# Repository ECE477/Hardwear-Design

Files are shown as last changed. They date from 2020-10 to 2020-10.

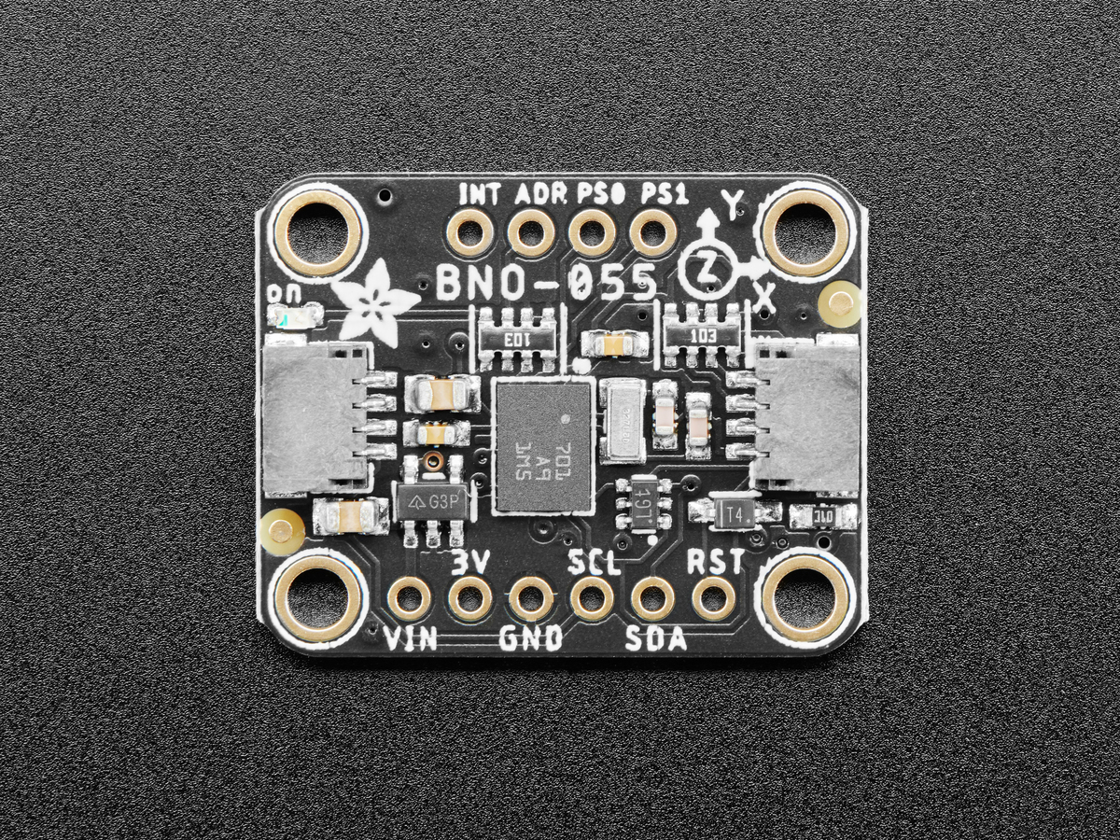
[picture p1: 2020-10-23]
Docs/Adafruit-BNO055-Breakout-PCB-master/Adafruit-BNO055-Breakout-PCB-master/assets/4646.jpg

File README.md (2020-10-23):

# Hardwear Design
Schematic and PCB

## PCB Checklist
### 1 Parts Completion Check
- [x] All major componenets included (ie. Micro, Power Supply, Regulation, Battery Management, IMU, GPS, LoRa, TOLED, Push Buttons, Reset Button, Signal LEDS)
- [x] All support components included (ie. Micro minimum connections, Testing Circuit, Support components package and value(R,Caps,Ind), Application circuits)
#### Other
- [x] Progamming Header 
- [x] Reset Circuit
- [x] Power Connectors
- [x] Mounting holes
- [x] Heartbeat LED
- [x] Debugging LEDs (Transmit LED)
### 2 PCB Footprint Verification Check
- [x] All parts fir on 1:1 scale printout of PCB
### 3 Parts Placement Check
- [x] Oscillator close to Micro? (N/A)
- [x] Decoupling caps close to/under related ICs?
- [x] Connectors on board edges?
- [x] Parts grouped by system and/or in reasonable way that minimizes routing?
### 4 Mechanical/Space Conflict Check:
- [x] Has x- and y- footprint space around electrical pins and pads of all parts been accounted for?
- [x] Has z-height of all parts been accounted for?
- [x] Has clearance been provided for the bolt heads of all mounting holes?
- [x] Have connectors been placed on the outer edges of boards where appropriate? Are they overhanging edges of boards where appropriate? Are they oriented in the correct direction?
- [x] Are all mounting and mechanical support holes free of traces and other electrical items?
### 5 Routing Completion Check:
- [x] All traces routed? (In Eagle, the ratsnest command will say “nothing to do”)
- [x] Oscillator traces clear of interfering signals?
- [x] Traces of appropriate widths to handle current being passed? (Including power traces)
- [x] Traces entering pads at 90-degree angles (or 45 degree angles, where appropriate)?
### 6 Routing Minimization Check:
- [x] Trace lengths have been minimized where possible?
- [x] Octagonal (45-degree constrained) layout mode has been utilized, where possible?
- [x] Right angles have been removed, except where necessary?
- [x] Acute angles have been eliminated from all board routing?
### 7 Via Minimization Check:
- [x] Vias have been eliminated to extent reasonable?
- [x] Signal planes on opposite sides of boards are connected by vias at reasonable intervals?
- [x] Signal Plane Check:
- [x] Signal planes have been included, where reasonable?
- [x] Analog ground (AGND), has been separated from the main ground net in accordance with microcontroller datasheets?
- [x] Isolation on all signal planes has been set to at least 12 mils?
### 9 Silkscreen check
- [x] Silkscreen labels have been provided for all component IDs and connector signal names?
- [x] Silkscreen labels have been appropriately placed near components, but not on top of pads or pins?
- [x] Pin 1 of all ICs and other polarity-sensitive components (such as diodes) is clearly marked?
- [x] Board silkscreen layer includes course and team number "ECE477 Group <x>"?
- [x] Board silkscreen layer includes names of all team members, if possible?
- [x] Board silkscreen layer includes a descriptive name to identify the board?
- [x] Board silkscreen layer includes a revision number and/or last modified date?
### 10 Gerber Check
- [x] Gerber files have been inspected by a gerber viewer program (e.g. gerbv) to check for any
last-minute software CAM-processing defects

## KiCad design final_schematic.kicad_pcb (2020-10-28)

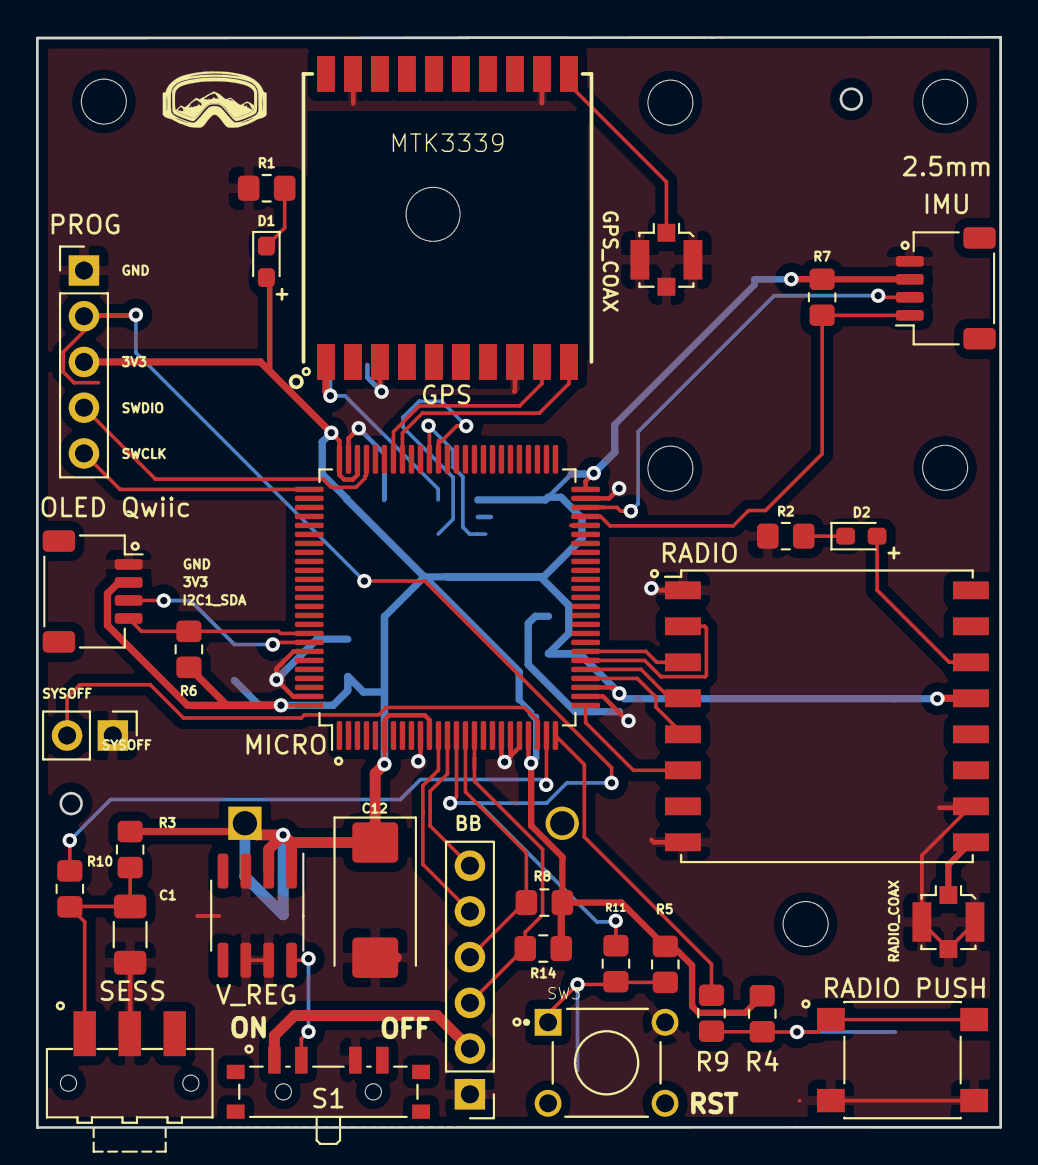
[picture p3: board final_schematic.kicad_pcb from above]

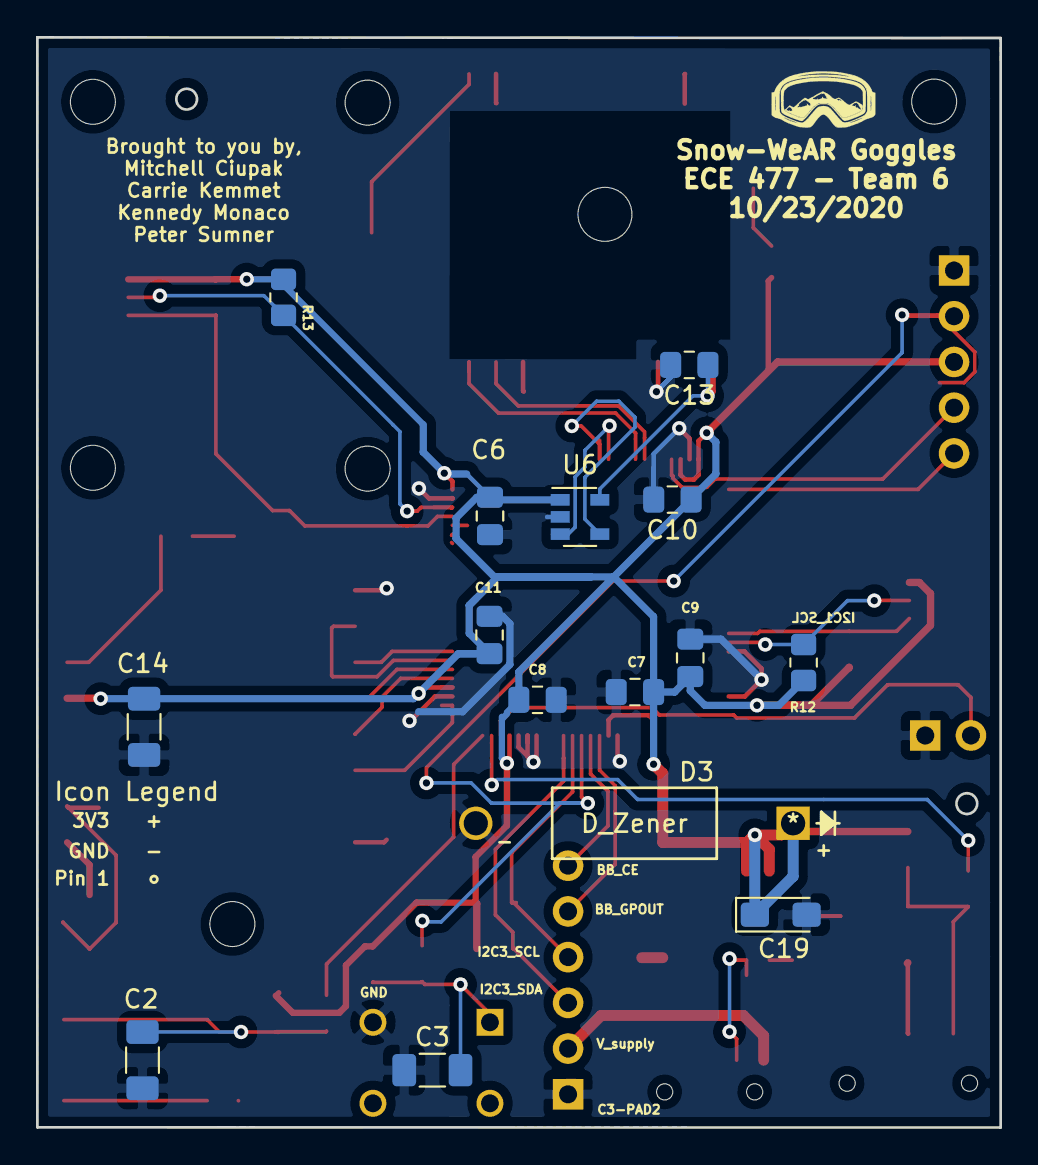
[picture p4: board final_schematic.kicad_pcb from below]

Board: 2 copper layers, 53.5 x 60.6 mm, 47 parts (15 on the bottom side), 36 nets.

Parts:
2.5mm: 2.5mm; MountingHole_2.5mm
BB: Battery Babysitter; PinHeader_1x06_P2.54mm_Vertical
C1, C2, C3: 1uF; C_1206_3216Metric_Pad1.33x1.80mm_HandSolder
C6, C7, C8, C9, C10, C11, C13: 0.1uF; C_0805_2012Metric_Pad1.18x1.45mm_HandSolder
C12: 3.3uF; CP_EIA-7343-15_Kemet-W_Pad2.25x2.55mm_HandSolder
C14: 10uF; C_1206_3216Metric_Pad1.33x1.80mm_HandSolder
C19: .1uF; CP_EIA-3216-10_Kemet-I_Pad1.58x1.35mm_HandSolder
D1: LED_HEARTBEAT_R1; D_0603_1608Metric_Pad1.05x0.95mm_HandSolder
D2: LED_TRANSMIT_G1; D_0603_1608Metric_Pad1.05x0.95mm_HandSolder
D3: D_Zener; 1N5355BRLG
GPS: MTK3339; FGPMMOPA6H
IMU: IMU_QWIIC; JST_SH_SM04B-SRSS-TB_1x04-1MP_P1.00mm_Horizontal
J8: GPS_COAX; U.FL_Molex_MCRF_73412-0110_Vertical
MICRO: STM32L476VGTx; LQFP-100_14x14mm_P0.5mm
OLED Qwiic: OLED Qwiic; JST_SH_SM04B-SRSS-TB_1x04-1MP_P1.00mm_Horizontal
PROG: PROG; PinHeader_1x05_P2.54mm_Vertical
R1, R2, R9, R10, R11: 62; R_0805_2012Metric_Pad1.20x1.40mm_HandSolder
R3, R4, R5, R6, R7, R8, R12, R13, R14: 10k; R_0805_2012Metric_Pad1.20x1.40mm_HandSolder
RADIO: RFM95W-868S2; HOPERF_RFM9XW_SMD
RADIO PUSH: SW_Push_RADIO; SW_SPST_PTS645
RADIO_COAX: LoRa_Conn_Coaxial; U.FL_Molex_MCRF_73412-0110_Vertical
S1: ON/OFF-SWITCH; SW_SP3T_PCM13
SESS: SW_Push_SESS; SW_SPDT_CK-JS102011SAQN
SW3: SW_Push_RST; SW_1825910-6-4
SYSOFF: BB_SYSOFF; PinHeader_1x02_P2.54mm_Vertical
U6: TC2014-3.3VxCTTR; SOT-23-5
V_REG: LT1129-3.3_SO8; SOIC-8_3.9x4.9mm_P1.27mm

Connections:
3V3: C6.1, C7.1, C8.1, C9.1, C10.1, C11.1, C12.1, C14.2, C19.1, D1.2, D3.1, IMU.3, MICRO.6, MICRO.11, MICRO.22, MICRO.28, MICRO.50, MICRO.73, MICRO.75, MICRO.100, OLED Qwiic.2, PROG.3, R3.1, R4.1, R5.1, R6.1, R7.1, R8.1, R12.1, R13.1, R14.1, RADIO.13, U6.1, V_REG.1, V_REG.2
BB_CE: BB.6, MICRO.13
BB_GPOUT: BB.5, MICRO.12
BB_Out: S1.2, V_REG.8
CS_LORA: MICRO.29, RADIO.5
DIO0: D2.2, RADIO.14
GND: BB.1, C1.1, C2.1, C3.1, C6.2, C7.2, C8.2, C9.2, C10.2, C11.2, C12.2, C13.2, C14.1, C19.2, D3.2, GPS.3, GPS.8, GPS.12, GPS.19, IMU.4, J8.2, MICRO.10, MICRO.19, MICRO.20, MICRO.21, MICRO.27, MICRO.49, MICRO.74, MICRO.94, MICRO.99, OLED Qwiic.1, PROG.1, R1.1, R2.1, RADIO.1, RADIO.8, RADIO.10, RADIO PUSH.2, RADIO_COAX.2, S1.3, SESS.2, SW3.2, SYSOFF.1, U6.2, V_REG.3, V_REG.6, V_REG.7
GPS_Vin: C13.1, GPS.1, U6.5
I2C1_SCL: MICRO.92, OLED Qwiic.4, R6.2
I2C1_SDA: MICRO.93, OLED Qwiic.3, R12.2
I2C2_SCL: IMU.1, MICRO.47, R7.2
I2C2_SDA: IMU.2, MICRO.48, R13.2
I2C3_SCL: BB.4, MICRO.15, R8.2
I2C3_SDA: BB.3, MICRO.16, R14.2
LDO_ERR: MICRO.64, U6.4
LDO_SHDN: MICRO.65, U6.3
LoRa_RST: MICRO.26, RADIO.6
NRST: MICRO.14, PROG.2, R11.1
unnamed: C1.2, R3.2, R10.2, SESS.1
unnamed: C2.2, R4.2, R9.2, RADIO PUSH.1
unnamed: C3.2, R5.2, R11.2, SW3.1
unnamed: D1.1, R1.2
unnamed: D2.1, R2.2
unnamed: GPS.11, J8.1
unnamed: RADIO.9, RADIO_COAX.1
SPI1_MISO: MICRO.31, RADIO.2
SPI1_MOSI: MICRO.32, RADIO.3
SPI1_SCK: MICRO.30, RADIO.4
SWCLK: MICRO.76, PROG.5
SWDIO: MICRO.72, PROG.4
SYSOFF: MICRO.23, SYSOFF.2
USART_RX: GPS.9, MICRO.69
USART_TX: GPS.10, MICRO.68
V_supply: BB.2, S1.1
radio_btn: MICRO.25, R9.1
session_btn: MICRO.24, R10.1

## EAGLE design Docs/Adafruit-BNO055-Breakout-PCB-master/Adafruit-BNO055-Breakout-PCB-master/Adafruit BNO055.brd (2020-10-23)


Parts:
C1, C2: 22pF; 0805-NO
C3: 0.1uF; 0805-NO
C4: 0.1uF; 0805_10MGAP
C5: 10uF; 0805-NO
C6: 10uF; 0805_10MGAP
D1: 1n4148; SOD-323
FID1, FID2: FIDUCIAL""; FIDUCIAL_1MM
JP1: HEADER-1X676MIL; 1X06_ROUND_76
JP2: HEADER-1X476MIL; 1X04_ROUND_76
Q1, Q2: BSS138; SOT23-WIDE
R3, R4, R5, R6, R7, R10: 10K; 0805-NO
R8, R9: 10K; _0805MP
U1: MIC5225-3.3; SOT23-5
U$2: BNO055
U$29, U$30, U$31, U$32: MOUNTINGHOLE2.5_THICK; MOUNTINGHOLE_2.5_PLATED_THICK
Y1: 32.768kHz; CRYSTAL_8X3.8

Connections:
3.3V: C4.2, C6.1, JP1.2, Q1.1 (G), Q2.1 (G), R6.2, R7.2, R10.2, U1.5 (OUT), U$2.3 (VDD), U$2.4 (NBOOT_LOAD_PIN), U$2.28 (VDDIO)
5.0V: C5.1, JP1.1, R8.2, R9.2, U1.1 (IN), U1.3 (EN)
GND: C1.1, C2.1, C3.1, C4.1, C5.2, C6.2, JP1.3, R3.2, R4.2, R5.2, U1.2 (GND), U$2.2 (GND), U$2.10 (PIN10(GND)), U$2.15 (PIN15(GND)), U$2.16 (PIN16(GND)), U$2.18 (COM2(GND)), U$2.25 (GND)
I2CADDR_3V: JP2.4, R5.1, U$2.17 (COM3/I2C_ADDR)
INT_3V: JP2.3, U$2.14 (INT)
unnamed: C1.2, U$2.27 (XIN32), Y1.P$4 (2)
unnamed: C2.2, U$2.26 (XOUT32), Y1.P$1 (1)
unnamed: C3.2, U$2.9 (CAP)
NRESET_3V: D1.A, R10.1, U$2.11 (NRESET)
PS0_3V: JP2.1, R3.1, U$2.6 (PS0)
PS1_3V: JP2.2, R4.1, U$2.5 (PS1)
RST_5V: D1.C, JP1.6
SCL_3V: Q2.2 (S), R7.1, U$2.19 (COM1/SCL/RX)
SCL_5V: JP1.5, Q2.3 (D), R9.1
SDA_3V: Q1.2 (S), R6.1, U$2.20 (COM0/SDA/TX)
SDA_5V: JP1.4, Q1.3 (D), R8.1



Board: 2 copper layers, 26.7 x 20.3 mm, 31 parts (2 on the bottom side), 16 nets.

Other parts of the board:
U$3: PCBFEAT-REV-040
U$28: ADAFRUIT_TEXT_20MM
U$33: ADAFRUIT_2.5MM

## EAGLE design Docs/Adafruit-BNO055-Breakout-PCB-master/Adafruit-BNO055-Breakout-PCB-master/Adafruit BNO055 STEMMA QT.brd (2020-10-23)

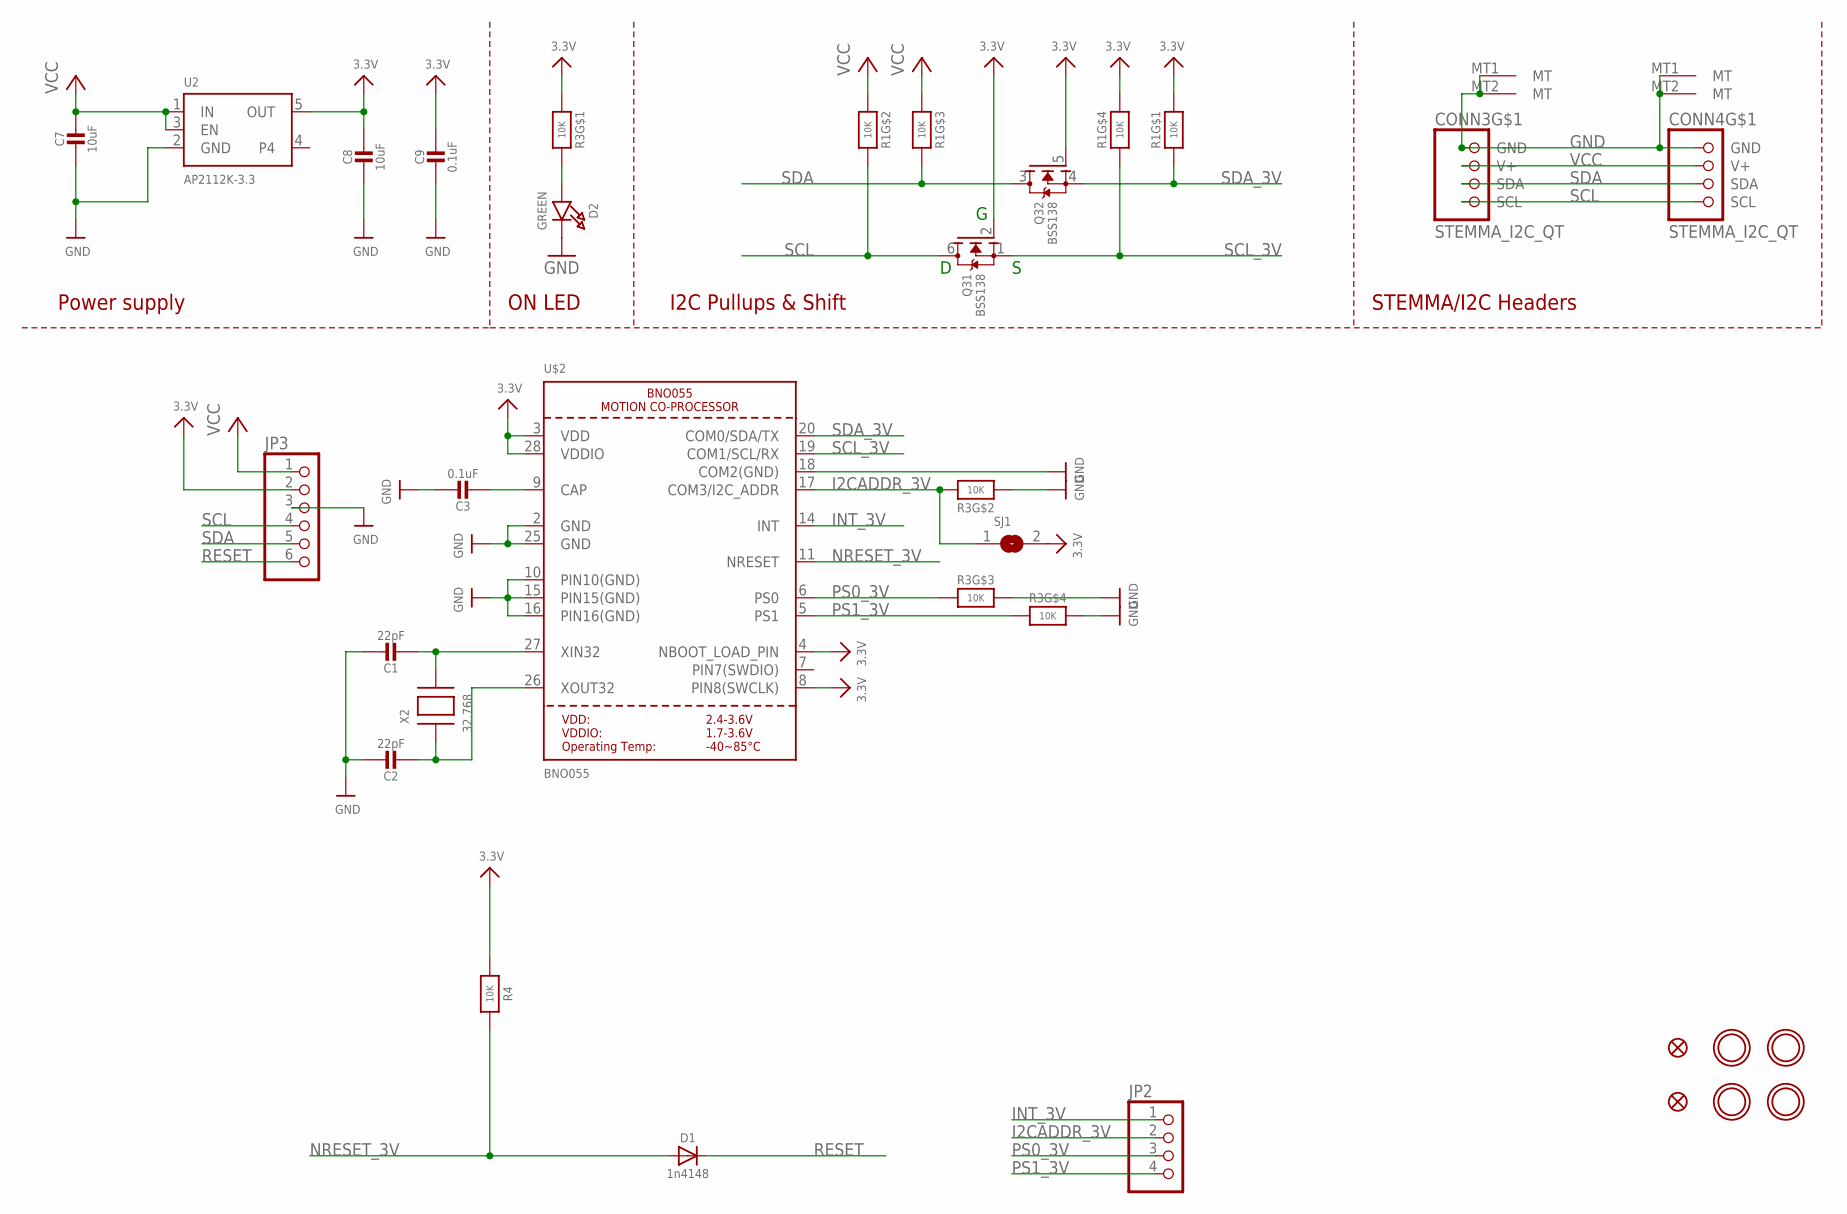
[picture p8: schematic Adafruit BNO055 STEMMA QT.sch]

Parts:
C1, C2: 22pF; 0603-NO
C3, C9: 0.1uF; 0603-NO
C7, C8: 10uF; 0805-NO
CONN3, CONN4: STEMMA_I2C_QT; JST_SH4
D1: 1n4148; SOD-323
D2: GREEN; CHIPLED_0603_NOOUTLINE
FID3, FID4: FIDUCIAL_1MM
JP2: HEADER-1X476MIL; 1X04_ROUND_76
JP3: HEADER-1X670MIL; 1X06_ROUND_70
Q3: BSS138; SOT363
R1, R3: 10K; RESPACK_4X0603
R4: 10K; 0603-NO
SJ1: SOLDERJUMPER; SOLDERJUMPER_ARROW_NOPASTE
U2: AP2112K-3.3; SOT23-5
U$2: BNO055
U$45, U$46, U$48, U$49: MOUNTINGHOLE2.5; MOUNTINGHOLE_2.5_PLATED
X2: 32.768; XTAL3215

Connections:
3.3V: C8.1, C9.1, JP3.2, Q3.2 (G), Q3.5 (G), R1.1, R1.4 (1), R3.1, R4.1, SJ1.2, U2.5 (OUT), U$2.3 (VDD), U$2.4 (NBOOT_LOAD_PIN), U$2.8 (PIN8(SWCLK)), U$2.28 (VDDIO)
GND: C1.1, C2.1, C3.1, C7.2, C8.2, C9.2, CONN3.1 (GND), CONN3.MT1 (MT), CONN3.MT2 (MT), CONN4.1 (GND), CONN4.MT1 (MT), CONN4.MT2 (MT), D2.C, JP3.3, R3.2 (1), R3.5 (2), R3.6 (2), U2.2 (GND), U$2.2 (GND), U$2.10 (PIN10(GND)), U$2.15 (PIN15(GND)), U$2.16 (PIN16(GND)), U$2.18 (COM2(GND)), U$2.25 (GND)
I2CADDR_3V: JP2.2, R3.7 (2), SJ1.1, U$2.17 (COM3/I2C_ADDR)
INT_3V: JP2.1, U$2.14 (INT)
unnamed: C1.2, U$2.27 (XIN32), X2.P$2
unnamed: C2.2, U$2.26 (XOUT32), X2.P$1
unnamed: C3.2, U$2.9 (CAP)
unnamed: D2.A, R3.8 (2)
NRESET_3V: D1.A, R4.2, U$2.11 (NRESET)
PS0_3V: JP2.3, R3.3 (1), U$2.6 (PS0)
PS1_3V: JP2.4, R3.4 (1), U$2.5 (PS1)
RESET: D1.C, JP3.6
SCL: CONN3.4 (SCL), CONN4.4 (SCL), JP3.4, Q3.6 (D), R1.7 (2)
SCL_3V: Q3.1 (S), R1.5 (2), U$2.19 (COM1/SCL/RX)
SDA: CONN3.3 (SDA), CONN4.3 (SDA), JP3.5, Q3.3 (D), R1.6 (2)
SDA_3V: Q3.4 (S), R1.8 (2), U$2.20 (COM0/SDA/TX)
VCC: C7.1, CONN3.2 (V+), CONN4.2 (V+), JP3.1, R1.2 (1), R1.3 (1), U2.1 (IN), U2.3 (EN)

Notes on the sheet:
I2C Pullups & Shift
STEMMA/I2C Headers
ON LED
Power supply

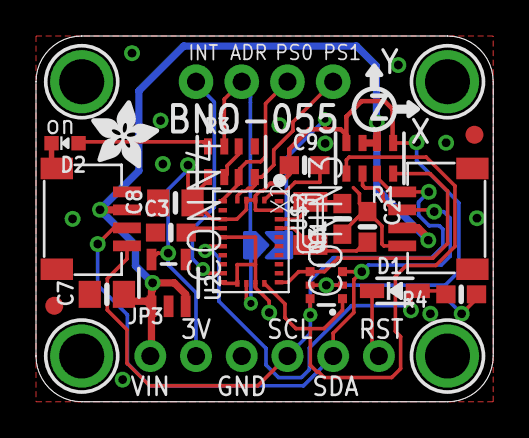
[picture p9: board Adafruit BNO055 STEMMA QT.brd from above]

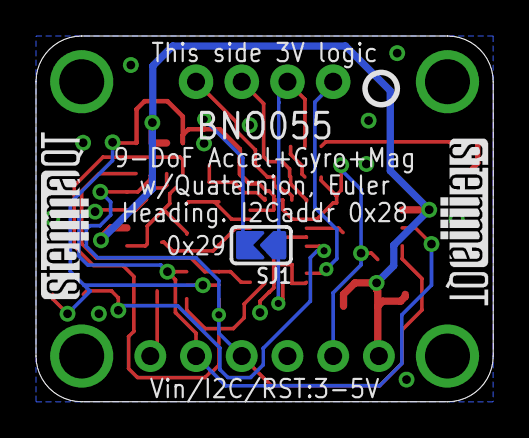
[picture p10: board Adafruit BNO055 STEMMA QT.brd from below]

Board: 2 copper layers, 25.4 x 20.3 mm, 30 parts (4 on the bottom side), 17 nets.

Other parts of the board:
U$51: ADAFRUIT_3.5MM
U$52: PCBFEAT-REV-040
U$53, U$54: STEMMAQT

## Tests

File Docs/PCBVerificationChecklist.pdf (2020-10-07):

Systematic PCB Verification Approach:

### 1. Parts Completion Check:

a. All major components included?
- Microcontroller/FPGA/SoC/Microprocessor/CPLD?
- Power supply? Regulation? Battery Management?
- Sensors?
- User interface elements? (LCDs, buttons, switches, etc.)
- Actuator drivers and control? (Motor control? LED driver circuitry? Audio filters and amplifiers? Etc. etc. etc.)
b. All support components included?
- Microcontroller system guidelines and/or minimum connection requirements followed?
- Application circuits and/or relevant app notes for all major components followed?
- Support components proper package as well as value? (Power circuit support components designed to handle necessary voltages and currents?)
c. Other components included?
- Programming header?
- Reset circuit?
- Power connector(s)?
- Mounting holes?
- Power indicator(s)?
- Heartbeat LED?
- Oscillator/clocking circuitry?
- Debugging LEDs or interfaces?

### 2. PCB Footprint Verification Check:

a. All parts fit on 1:1 scale printout of PCB

### 3. Parts Placement Check:

a. Oscillator close to microcontroller?
b. Decoupling caps close to/under related ICs?
c. Connectors on board edges?
d. Parts grouped by system and/or in reasonable way that minimizes routing?

### 4. Mechanical/Space Conflict Check:

a. Has x- and y- footprint space around electrical pins and pads of all parts been accounted for?
b. Has z-height of all parts been accounted for?
c. Has clearance been provided for the bolt heads of all mounting holes?
d. Have connectors been placed on the outer edges of boards where appropriate? Are they overhanging edges of boards where appropriate? Are they oriented in the correct direction?
e. Are all mounting and mechanical support holes free of traces and other electrical items?

### 5. Routing Completion Check:

a. All traces routed? (In Eagle, the ratsnest command will say “nothing to do”)
b. Oscillator traces clear of interfering signals?
c. Traces of appropriate widths to handle current being passed? (Including power traces)
d. Traces entering pads at 90-degree angles (or 45 degree angles, where appropriate)?

### 6. Routing Minimization Check:

a. Trace lengths have been minimized where possible?
b. Octagonal (45-degree constrained) layout mode has been utilized, where possible?
c. Right angles have been removed, except where necessary?
d. Acute angles have been eliminated from all board routing?

### 7. Via Minimization Check:

a. Vias have been eliminated to extent reasonable?
b. Signal planes on opposite sides of boards are connected by vias at reasonable intervals?

### 8. Signal Plane Check:

a. Signal planes have been included, where reasonable?
b. Analog ground (AGND), has been separated from the main ground net in accordance with microcontroller datasheets?
c. Isolation on all signal planes has been set to at least 12 mils?

### 9. Silkscreen check

a. Silkscreen labels have been provided for all component IDs and connector signal names?
b. Silkscreen labels have been appropriately placed near components, but not on top of pads or pins?
c. Pin 1 of all ICs and other polarity-sensitive components (such as diodes) is clearly marked?
d. Board silkscreen layer includes course and team number (ECE477 Group <x>)?
e. Board silkscreen layer includes names of all team members, if possible?
f. Board silkscreen layer includes a descriptive name to identify the board?
g. Board silkscreen layer includes a revision number and/or last modified date?

### 10. Gerber Check

a. Gerber files have been inspected by a gerber viewer program (e.g. gerbv) to check for any last-minute software CAM-processing defects

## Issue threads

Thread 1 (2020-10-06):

Add connectors

ckemmet, 2020-10-06:
Need a connector for programming microcontroller
Add connector to battery babysitter module

ckemmet, 2020-10-06:
Helpful links:
[Battery babysitter hookup guide](https://learn.sparkfun.com/tutorials/battery-babysitter-hookup-guide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)

[An example of what we need for the PCB](https://www.adafruit.com/product/752#technical-details)

[Connecting your debugger](https://stm32-base.org/guides/connecting-your-debugger.html)

[Another guide](http://vedder.se/2014/12/connecting-a-programmerdebugger-my-custom-stm32-pcbs/)

[Another guide](https://predictabledesigns.com/tutorial-how-to-design-your-own-custom-microcontroller-board-video-part1/)

Closed 2020-10-06.

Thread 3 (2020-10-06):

Add LED indicators

ckemmet, 2020-10-06:
A light for power own, for radio enable maybe

ckemmet, 2020-10-06:
Added but still need LED values so that series resistor values can be determined.

Closed 2020-10-08.

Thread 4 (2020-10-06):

Replace gauge and charger with connector to Battery Babysitter

ckemmet, 2020-10-06:
How do we do that? Idk. I'll figure it out.

ckemmet, 2020-10-06:
Gonna need a long supply and gnd wire between babysitter and battery. Decrease performance? Idk. I should do research

Closed 2020-10-06.

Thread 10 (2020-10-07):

R9 and R10 need resistor values

mitchellciupak, 2020-10-07:
Please assign resistor values, sybol #'s 37,38

mitchellciupak, 2020-10-07:
Per @ckemmet make 48 ohm placeholder

ckemmet, 2020-10-09:
62 ohms

Closed 2020-10-09.

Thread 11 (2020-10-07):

LoRa IC - Could only find  breakout board

mitchellciupak, 2020-10-07:
This is the only thing we can find to buy, but we just want the chip off it
https://www.digikey.com/en/products/detail/rf-solutions/rfm95w-868s2/5051755

IF FIXED UPDATE
https://github.com/ECE477/Hardwear-Design/wiki/Primary-Component-Footprint-Assignments

ckemmet, 2020-10-09:
This is fine. The whole SMD module should be used, and that's the footprint that we have.

Closed 2020-10-09.

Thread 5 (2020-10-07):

Need Completely Annotated NetList

mitchellciupak, 2020-10-07:
1. Go thru checklist section one and confirm all components are present
2. Create connections to micro or other necessary connections
3. Test if NetList is complete by clicking "Generate NetList" *top row of icons 5th from the right with the words "Net" in it.
3a. In the Pcbnew tab click 'Generate Netlist'
** If it doesn't give you an "Exporting the netlist requires a completely annotated schematic" error then I think we are good.

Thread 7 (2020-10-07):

BNO-055 (IMU) VDDIO vs. VDD

mitchellciupak, 2020-10-07:
https://cdn-learn.adafruit.com/assets/assets/000/036/832/original/BST_BNO055_DS000_14.pdf
^ Datasheet for BNO-055 (See page 12 for Electrical Overview and page 98 for I2C connection diagram(our connection))

- Can we connect VDDIO and VDD to the same voltage source? It looks like they are doing it on our breakout (https://www.adafruit.com/product/2472)

mitchellciupak, 2020-10-07:
More docs --> https://learn.adafruit.com/adafruit-bno055-absolute-orientation-sensor/downloads

monacok21, 2020-10-07:
According to the datasheet, VDD has to be between 2.4 to 3.6 and VDDIO has to be between 1.7 and 3.6 so connecting both to 3.3V should be fine.

ckemmet, 2020-10-09:
They didn't seem to have a problem with it at all. I'm closing this.

Closed 2020-10-09.

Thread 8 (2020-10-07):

TOLED - Can we just supply pinout to breakout board?

mitchellciupak, 2020-10-07:
Given that the TOLED is not placed near the PCB we have decided to provide pin headers in our design that will be connected to the Sparkfun breakout

We should consult the course staff on this decision

Datasheet in this repos wiki
https://github.com/ECE477/Hardwear-Design/wiki

Hookup Guide
https://learn.sparkfun.com/tutorials/transparent-graphical-oled-breakout-hookup-guide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

Product Page
https://www.sparkfun.com/products/15173

monacok21, 2020-10-07:
Agreed. We just need to be sure that the jumpers are properly severed to use SPI mode.

Closed 2020-10-08.

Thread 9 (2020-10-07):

IMU PS1/Pin5 routed to VDDIO? *Need Confrim

mitchellciupak, 2020-10-07:
Data Sheet page 98 https://learn.adafruit.com/bno055-absolute-orientation-sensor-with-raspberry-pi-and-beaglebone-black/hardware

Hookup Guide: https://learn.adafruit.com/bno055-absolute-orientation-sensor-with-raspberry-pi-and-beaglebone-black/hardware

monacok21, 2020-10-07:
No, according to the datasheet PS1 and PS0 should be connected to GND for I2C mode.
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

mitchellciupak, 2020-10-08:
Looks updated correctly in schematic and pcb file. Thanks @monacok21

Closed 2020-10-08.

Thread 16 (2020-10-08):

Schematic Fixes

monacok21, 2020-10-08:
1. Add 100ohm resistors in series to Micro to avoid shocking users
2. Remove GPS LED to avoid unnecessary current draw
3. Fix Flag Labels
4. Use Qwiic connector for OLED
5. Replace 1 pin headers with 2 pin - need ground reference

ckemmet, 2020-10-09:
1. Fixed with "schematic issue partial fix" commit
2. Deemed unnecessary, we can choose to drive it or not
3. Kennedy fixed earlier
4. Needs fixing
5. Fixed with "schematic issue partial fix" commit

ckemmet, 2020-10-09:
Making a separate issue for one remaining item (step 4)

Closed 2020-10-09.

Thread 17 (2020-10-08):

PCB Layout Reminders

monacok21, 2020-10-08:
1. Decoupling capacitors should be as close as possible to pwr/gnd pins (usually placed on opposite side of ICs)
2. On/Off switch should hang off board
3. Don't ground fill where antenna connections are
4. Orthogonal Routing
5. Layout traces at desired widths (don't layout small then increase trace widths)

mitchellciupak, 2020-10-08:
6. All user pushbuttons should contain a 10-100 ohm resistor in series to discharge current that a user could be carrying.
7. JTAG -> 4 pin connector
8. Remove GPS LED
9. Update Naming Convention
10. Don't use any single pin connections (should have reference to ground)
11. Make sure all connectors are polarized (cannot be put in backward)

mitchellciupak, 2020-10-11:
Completed: 8, 9, 10, 6, 7(?)
Will use in PCB design: 1,2,3,4,5,11

mitchellciupak, 2020-10-11:
Breaking into sperate issues

Closed 2020-10-11.

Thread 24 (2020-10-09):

Add voltage regulator to the schematic

ckemmet, 2020-10-09:
Turns out the battery babysitter works best with a voltage regulator

mitchellciupak, 2020-10-11:
Completed by @ckemmet

Closed 2020-10-11.

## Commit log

2020-10-02 first schematic commit
    [final_schematic.sch]
2020-10-06 made original draft look neater. Now I need to actually do work
    [final_schematic.sch]
2020-10-06 Added connectors for battery babysitter and jtag debugger
    [final_schematic.sch]
2020-10-06 added buttons, switch, and 2 leds. Do not have led specs so still need resistor values
    [final_schematic.sch]
2020-10-06 included session push this time. Still ugly
    [final_schematic.sch]
2020-10-07 README.md -> PCB Checklist
2020-10-07 hi Kennedy
    [final_schematic.sch]
2020-10-07 last minute backup before adding oled headers
    [final_schematic.sch]
2020-10-07 schematic finalized
    [final_schematic.sch]
2020-10-07 Minor changes to Schematic
2020-10-07 pls no more
    [final_schematic.sch]
2020-10-07 Updated footprint assignments
2020-10-07 added footprint library for GPS antenna and chip
2020-10-07 Footprint Assignments Completed
    [final_schematic.sch]
2020-10-07 PCB created
2020-10-07 Grouped Circuits/Re-arranged Schematic
    [final_schematic.sch]
2020-10-08 Updated Schematic from K improvements, also renamed
    [final_schematic.sch]
2020-10-08 all footprints added to .kicad_pcb
    [final_schematic.kicad_pcb, final_schematic.sch]
2020-10-08 Component Check Passed
    [final_schematic.kicad_pcb]
2020-10-08 IMU, LORA, and GPS organized
    [final_schematic.kicad_pcb]
2020-10-08 BB Pin Updates and Flag Updates
    [final_schematic.sch]
2020-10-08 Components spacialy assocsiated
    [final_schematic.kicad_pcb]
2020-10-08 Pre AI Routing Backup
    [final_schematic.kicad_pcb]
2020-10-08 preperation for the robotic wars
    [final_schematic.kicad_pcb]
2020-10-08 grounds and 3v3 mapped
    [final_schematic.kicad_pcb]
2020-10-08 Schematic edits
    [final_schematic.kicad_pcb, final_schematic.sch]
2020-10-09 schematic partial fix
    [final_schematic.sch]
2020-10-09 added voltage regulator because we need it
    [final_schematic.sch]
2020-10-09 remove gps led
2020-10-11 Schematic Update... again new file: 1825910-6.lib new file: 1825910-6.pro modified: final_schematic-cache.lib modified: final_schematic.sch new file: final_schematic.sch-bak new file: final_schematic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
2020-10-11 Schematic Update with correct resistor values modified: final_schematic.sch modified: final_schematic.sch-bak
    [final_schematic.sch]
2020-10-11 Update final_schematic.sch
    fixed EOL error
    [final_schematic.sch]
2020-10-12 pcb checkpoint
    [final_schematic.kicad_pcb, final_schematic.sch, final_schematic_OLD.kicad_pcb]
2020-10-12 PCB deconstruction
    [final_schematic.kicad_pcb, final_schematic.sch]
2020-10-12 latest and greatest
    [final_schematic.kicad_pcb]
2020-10-13 Update final_schematic.sch
    Removing EOL
    [final_schematic.sch]
2020-10-13 added larger footprints and zener diode
    [final_schematic.sch]
2020-10-13 Schematic FINAL modified: final_schematic-cache.lib modified: final_schematic.sch modified: final_schematic.sch-bak
    [final_schematic.sch]
2020-10-13 Please be right
    [final_schematic.sch]
2020-10-13 I think this is going well
    [final_schematic.kicad_pcb, final_schematic.sch, final_schematic_OLD.kicad_pcb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]
2020-10-13 yep real well
    [final_schematic.kicad_pcb]
2020-10-13 Routing Complete
    [final_schematic.kicad_pcb]
2020-10-13 Fill Added REVERT LOCATION
    [final_schematic.kicad_pcb]
2020-10-13 dimensions finalized
    [final_schematic.kicad_pcb]
2020-10-13 Design Rules Pass, more silkskin
    [final_schematic.kicad_pcb]
2020-10-13 Silkscreen is milkscreen
    [final_schematic.kicad_pcb]
2020-10-19 Cha Cha Cha Changes
    [final_schematic.kicad_pcb, final_schematic.sch]
2020-10-21 Todd Meeting Edits
    [final_schematic.sch]
2020-10-22 component update
    [final_schematic.kicad_pcb, final_schematic.sch]
2020-10-22 silkscreen changes
    [final_schematic.kicad_pcb]
2020-10-22 routing minimization
    [final_schematic.kicad_pcb]
2020-10-22 routing minimization peer review
    [final_schematic.kicad_pcb]
2020-10-23 final design, pre gerber
    [Adafruit BNO055 STEMMA QT.brd, Adafruit BNO055 STEMMA QT.sch, Adafruit BNO055.brd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]
2020-10-23 gerber files generated
    [final_schematic-B_Cu.gbr, final_schematic-B_Mask.gbr, final_schematic-B_Paste.gbr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]
2020-10-23 gerbv confirmed and scale for imu breakout
    [final_schematic-B_Cu.gbr, final_schematic-B_Mask.gbr, final_schematic-B_Paste.gbr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]
2020-10-27 fits babysitter now
    [final_schematic.kicad_pcb]
2020-10-28 gerber update
    [final_schematic-B_Cu.gbr, final_schematic-B_Mask.gbr, final_schematic-B_Paste.gbr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]

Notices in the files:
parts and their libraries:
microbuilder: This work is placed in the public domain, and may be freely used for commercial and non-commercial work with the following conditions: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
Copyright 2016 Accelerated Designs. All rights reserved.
